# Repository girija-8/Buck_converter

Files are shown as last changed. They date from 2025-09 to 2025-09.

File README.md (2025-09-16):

# LMR51450 Based 7.6V, 4A DC-DC Buck Converter
---
A 2-layer PCB design for a synchronous step-down (buck) converter based on the Texas Instruments' LMR51450. This project is designed to be a power supply for general-purpose electronics, capable of operating over a wide input voltage range.

---
## Key Specifications

| Parameter | Value |
| :--- | :--- |
| **Input Voltage** | 4V to 36V DC |
| **Output Voltage** | 7.6V DC |
| **Maximum Output Current** | 4A |
| **Switching Frequency** | 500 kHz |
| **IC** | LMR51450SDRRR |

---
## Hardware

The design is revolves around the LMR51450 IC and a power inductor suitable for the required current.

* **Main Controller IC:** Texas Instruments `LMR51450SDRRR` (36V, 5A Synchronous Buck Converter)
* **Power Inductor:** Wurth Elektronik `7443845030082` (8.2µH, 6.2A I<sub>rms</sub>, 9.5A I<sub>sat</sub>)
* **Input/Output Connectors:** 2-Position, 5.08mm Pitch Screw Terminals

A complete list of all components, including specific part numbers for resistors and capacitors, is available in the Bill of Materials.

---
## Project Structure
```
Buck_Converter_Project/
│
├── Files/
│   ├── Buck_Converter.csv.xlsx
│   ├── Buck_Converter.kicad_pcb
│   ├── Buck_Converter.kicad_pro
│   ├── Buck_Converter.kicad_sch
│   └── Buck_converter_BOM.pdf
│
├── Media/
│   ├── PCB.png
│   ├── PCB_bottom.png
│   ├── PCB_top_layer.png
│   └── Schematic.png
│
└── README.md
```
---
## Key Design Equations

The primary component values were determined using the following formulas from the LMR51450 datasheet.

#### Output Voltage Resistor Divider

The output voltage ($V_{OUT}$) is set by the feedback resistors $R_{FBT}$ and $R_{FBB}$ based on the internal 0.8V reference ($V_{REF}$).

$$
R_{FBT} = \frac{(V_{OUT} - V_{REF})}{V_{REF}} \times R_{FBB}
$$

#### Inductor Selection

The minimum inductance ($L_{MIN}$) is calculated based on the maximum input voltage, desired output current, and a chosen inductor ripple current factor ($K_{IND}$, typically 0.2-0.4).

$$
L_{MIN} = \frac{V_{IN\_MAX} - V_{OUT}}{I_{OUT} \times K_{IND}} \times \frac{V_{OUT}}{V_{IN\_MAX} \times f_{SW}}
$$

#### Output Capacitor Selection

The output capacitance ($C_{OUT}$) is chosen to meet requirements for both output voltage ripple and transient response during a load step.

* **Ripple based on ESR:**

    ```math
    \Delta V_{OUT\_ESR} = \Delta i_{L} \times ESR
    ```

* **Ripple based on Capacitance:**
  
    ```math
    \Delta V_{OUT\_C} = \frac{\Delta i_{L}}{8 \times f_{SW} \times C_{OUT}}
    ```

* **Minimum Capacitance for Transient Response:**

    ```math
    C_{OUT} > \frac{1}{2} \times \frac{6 \times (I_{OH} - I_{OL})}{f_{SW} \times \Delta V_{OUT\_SHOOT}}
    ```
---
## Design Files

This repository contains all the necessary files to review and manufacture the project, designed in KiCad.

* **`Buck_Converter.kicad_sch`**: The main schematic file.
* **`Buck_Converter.kicad_pcb`**: The final 2-layer PCB layout file.
* **`Buck_Converter.csv`**: The complete Bill of Materials (BOM) with manufacturer part numbers.
* **`Buck_Converter_BOM.pdf`**: Bill of Materials (BOM) in pdf format.
* **`Media/`**: A folder containing screenshots of the final schematic and PCB layout.

---
## Design Notes & Layout Strategy

This project was designed with a focus on robustness and performance, following best practices for switching power supply layout.

* **Wide Input Range:** The components, particularly the 8.2µH inductor, were selected to ensure stable operation across the full input voltage range of the IC (up to 36V).
* **2-Layer Design:**
    * **Top Layer (`F.Cu`):** All components are placed on the top layer. High-current paths (`VIN`, `VOUT`, `SW`) are implemented as wide copper pours to minimize resistance, inductance, and thermal stress. A "filler" ground pour is also used for additional shielding.
    * **Bottom Layer (`B.Cu`):** The entire bottom layer is dedicated to a solid, continuous ground plane. This provides a low-impedance return path for currents, which is critical for stability and low noise (EMI).
* **Thermal Management:** A dense grid of thermal vias is placed directly on the central thermal pad of the LMR51450 IC, connecting it to the bottom ground plane to effectively dissipate heat. Additional "stitching" vias are used throughout the board to strongly connect the top and bottom ground planes.
* **Routing:** All high-current connections were made with copper pours. Only the low-power signal traces for the feedback network were routed as thin traces.

---
## Media

*(**Instructions:** Replace these placeholders with your final screenshots inside the `Media` folder.)*

**Schematic:**
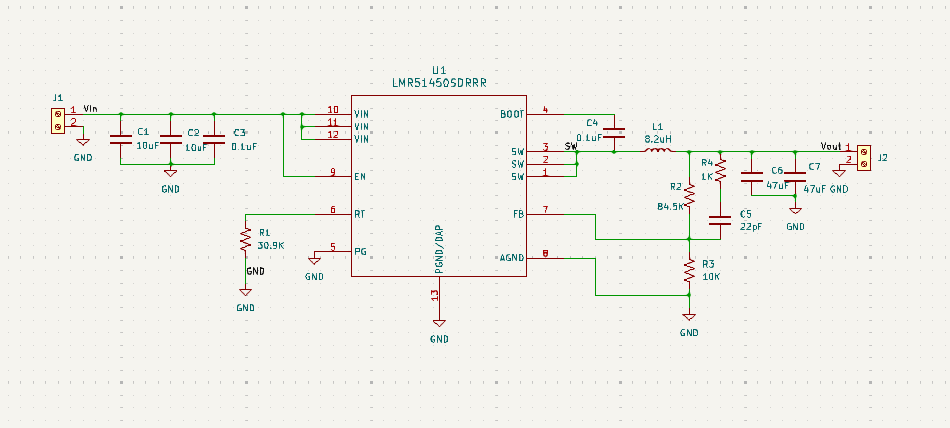
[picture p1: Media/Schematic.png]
Schematic


**PCB Layout (Top and Bottom Layers):**
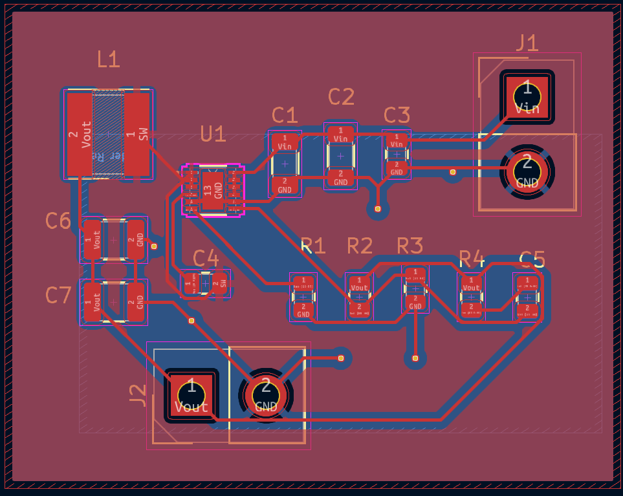
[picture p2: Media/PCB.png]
PCB Layout


---

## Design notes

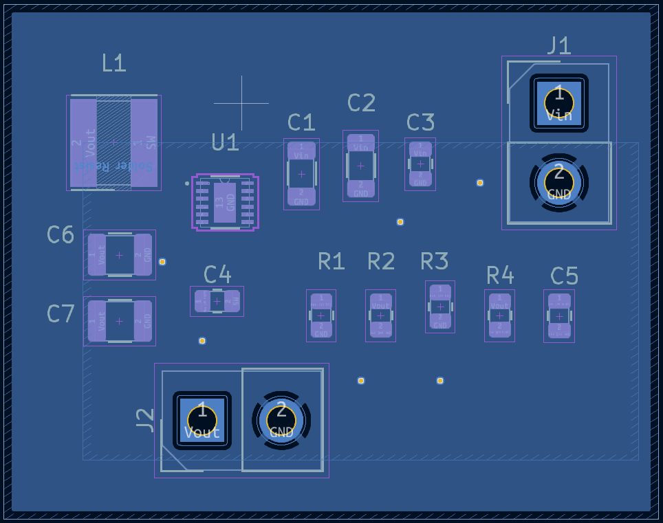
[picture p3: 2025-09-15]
Media/PCB_bottom.png

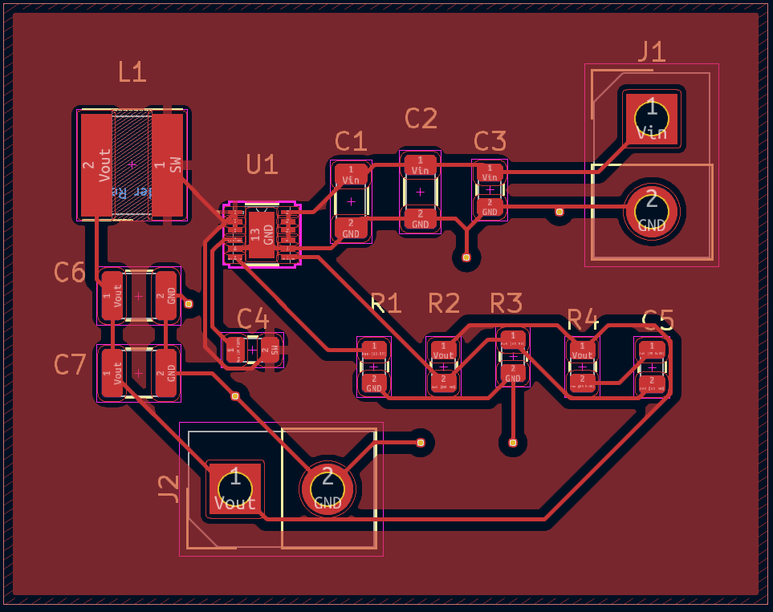
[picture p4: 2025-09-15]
Media/PCB_top_layer.png

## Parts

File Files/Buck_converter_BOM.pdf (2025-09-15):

Reference | Qty | Value | Part No | Manufacturer
C1,C2 | 2 10uF | C1206C104K5RAC7800 KEMET
C3 | 1 0.1uF | C0805C104K5RAC7800 KEMET
C4 | 1 0.1uF | C0805C104K3RAC7800 KEMET
C5 | 1 22pF | C0805C220J5GAC7800 KEMET
C6,C7 | 2 47uF | GRM32ER71A476KE15K Murata
J1,J2 | 2 Screw_Terminal_01x02 1757019 | Phoenix Contact
L1 | | 1 8.2uH | L-7443845030082 | Wurth Elektronik
R1 | | 1 30.9K | RC0805FR-0730K9L | Yageo
R2 | | 1 84.5K | RC0805FR-0784K5L | Yageo
R3 | | 1 10K | RC0805FR-0710KL | Yageo
R4 | | 1 1K | RC0805FR-071KL | Yageo
U1 | | 1 LMR51450SDRRR | LMR51450SDRRR | Texas Instruments

Description
1206 Size, 10µF, 50V, X7R Dielectric 0805 Size, 0.1µF, 50V, X7R Dielectric 0805 Size, 0.1µF, 25V, X7R Dielectric 0805 Size, 22pF, 50V, C0G Dielectric
1210 Size, 47µF, 25V, X7R Dielectric
Pluggable Terminal Blocks
IND, POWER, 8.2uH +/-20%, 6.1A, SMD, WE-MXGI 0805 Size, 30.9 kΩ, 1% Tolerance, 1/8W Power Rating 0805 Size, 84.5 kΩ, 1% Tolerance, 1/8W Power Rating 0805 Size, 10 kΩ, 1% Tolerance, 1/8W Power Rating 0805 Size, 1 kΩ, 1% Tolerance, 1/8W Power Rating IC, SYNC BUCK CONV, 4V-36V INPUT, 5A, WSON-12

Footprint
Capacitor_SMD:C_1206_3216Metric Capacitor_SMD:C_0805_2012Metric Capacitor_SMD:C_0805_2012Metric
Capacitor_SMD:C_0805_2012Metric
Capacitor_SMD:C_1210_3225Metric Connector_Samtec_HPM_THT:Samtec_HPM-02-01-x-S_Straight_1x02_Pitch5.08mm Inductor_SMD_Wurth1:L_Wurth_WE-MXGI-5030 Resistor_SMD:R_0805_2012Metric
Resistor_SMD:R_0805_2012Metric
Resistor_SMD:R_0805_2012Metric Resistor_SMD:R_0805_2012Metric KiCADv6:WSON_SDRRR_TEX

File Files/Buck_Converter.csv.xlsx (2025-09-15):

Reference | Qty | Value | Part No | Manufacturer | Description | Footprint
C1,C2 | 2 | 10uF | C1206C104K5RAC7800 | KEMET | 1206 Size, 10µF, 50V, X7R Dielectric | Capacitor_SMD:C_1206_3216Metric
C3 | 1 | 0.1uF | C0805C104K5RAC7800 | KEMET | 0805 Size, 0.1µF, 50V, X7R Dielectric | Capacitor_SMD:C_0805_2012Metric
C4 | 1 | 0.1uF | C0805C104K3RAC7800 | KEMET | 0805 Size, 0.1µF, 25V, X7R Dielectric | Capacitor_SMD:C_0805_2012Metric
C5 | 1 | 22pF | C0805C220J5GAC7800 | KEMET | 0805 Size, 22pF, 50V, C0G Dielectric | Capacitor_SMD:C_0805_2012Metric
C6,C7 | 2 | 47uF | GRM32ER71A476KE15K | Murata | 1210 Size, 47µF, 25V, X7R Dielectric | Capacitor_SMD:C_1210_3225Metric
J1,J2 | 2 | Screw_Terminal_01x02 | 1757019 | Phoenix Contact | Pluggable Terminal Blocks | Connector_Samtec_HPM_THT:Samtec_HPM-02-01-x-S_Straight_1x02_Pitch5.08mm
L1 | 1 | 8.2uH | L-7443845030082 | Wurth Elektronik | IND, POWER, 8.2uH +/-20%, 6.1A, SMD, WE-MXGI | Inductor_SMD_Wurth1:L_Wurth_WE-MXGI-5030
R1 | 1 | 30.9K | RC0805FR-0730K9L | Yageo | 0805 Size, 30.9 kΩ, 1% Tolerance, 1/8W Power Rating | Resistor_SMD:R_0805_2012Metric
R2 | 1 | 84.5K | RC0805FR-0784K5L | Yageo | 0805 Size, 84.5 kΩ, 1% Tolerance, 1/8W Power Rating | Resistor_SMD:R_0805_2012Metric
R3 | 1 | 10K | RC0805FR-0710KL | Yageo | 0805 Size, 10 kΩ, 1% Tolerance, 1/8W Power Rating | Resistor_SMD:R_0805_2012Metric
R4 | 1 | 1K | RC0805FR-071KL | Yageo | 0805 Size, 1 kΩ, 1% Tolerance, 1/8W Power Rating | Resistor_SMD:R_0805_2012Metric
U1 | 1 | LMR51450SDRRR | LMR51450SDRRR | Texas Instruments | IC, SYNC BUCK CONV, 4V-36V INPUT, 5A, WSON-12 | KiCADv6:WSON_SDRRR_TEX

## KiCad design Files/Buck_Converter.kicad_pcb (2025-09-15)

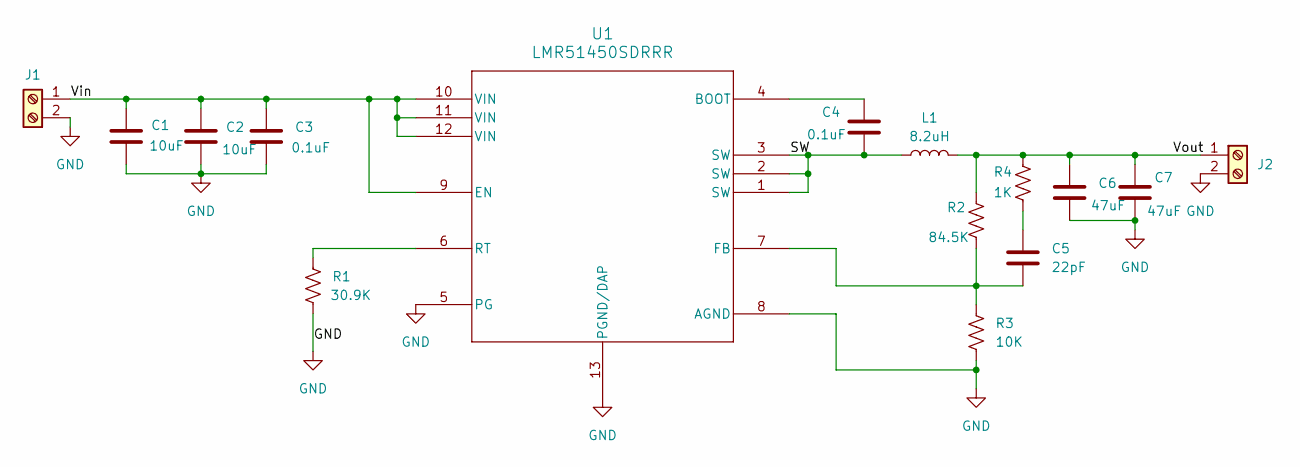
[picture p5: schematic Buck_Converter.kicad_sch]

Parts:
C1, C2: 10uF; C_1206_3216Metric
C3, C4: 0.1uF; C_0805_2012Metric
C5: 22pF; C_0805_2012Metric
C6, C7: 47uF; C_1210_3225Metric
J1, J2: Screw_Terminal_01x02; Samtec_HPM-02-01-x-S_Straight_1x02_Pitch5.08mm
L1: 8.2uH; L_Wurth_WE-MXGI-5030
R1: 30.9K; R_0805_2012Metric
R2: 84.5K; R_0805_2012Metric
R3: 10K; R_0805_2012Metric
R4: 1K; R_0805_2012Metric
U1: LMR51450SDRRR; WSON_SDRRR_TEX

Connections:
/SW: C4.2, L1.1, U1.1 (SW), U1.2 (SW), U1.3 (SW)
/Vin: C1.1, C2.1, C3.1, J1.1, U1.9 (EN), U1.10 (VIN), U1.11 (VIN), U1.12 (VIN)
/Vout: C6.1, C7.1, J2.1, L1.2, R2.1, R4.1
GND: C1.2, C2.2, C3.2, C6.2, C7.2, J1.2, J2.2, R1.2, R3.2, U1.5 (PG), U1.8 (AGND), U1.13 (PGND/DAP)
unnamed: C5.1, R4.2
unnamed: C4.1, U1.4 (BOOT)
unnamed: C5.2, R2.2, R3.1, U1.7 (FB)
unnamed: R1.1, U1.6 (RT)

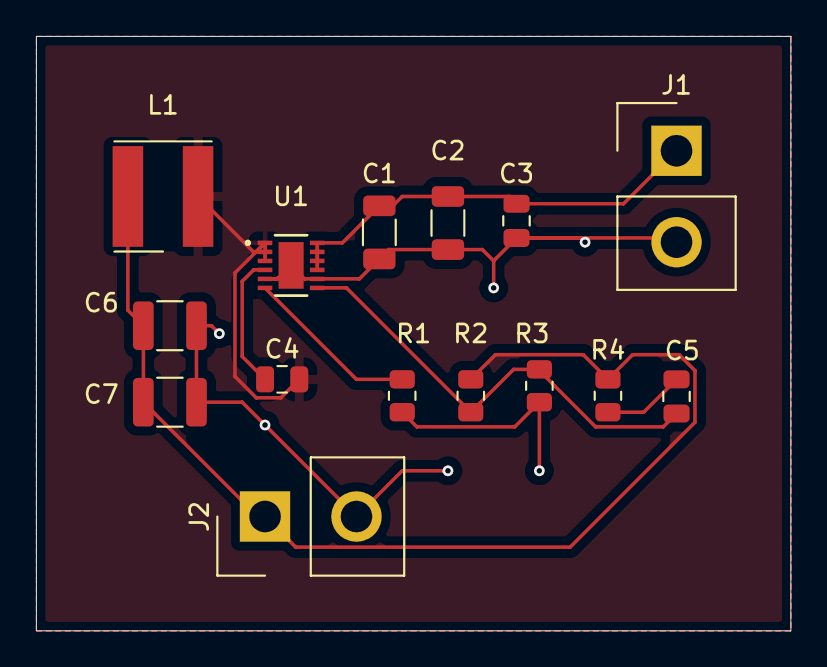
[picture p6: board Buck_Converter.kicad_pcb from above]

Board: 2 copper layers, 41.9 x 33.0 mm, 15 parts (0 on the bottom side), 8 nets.
